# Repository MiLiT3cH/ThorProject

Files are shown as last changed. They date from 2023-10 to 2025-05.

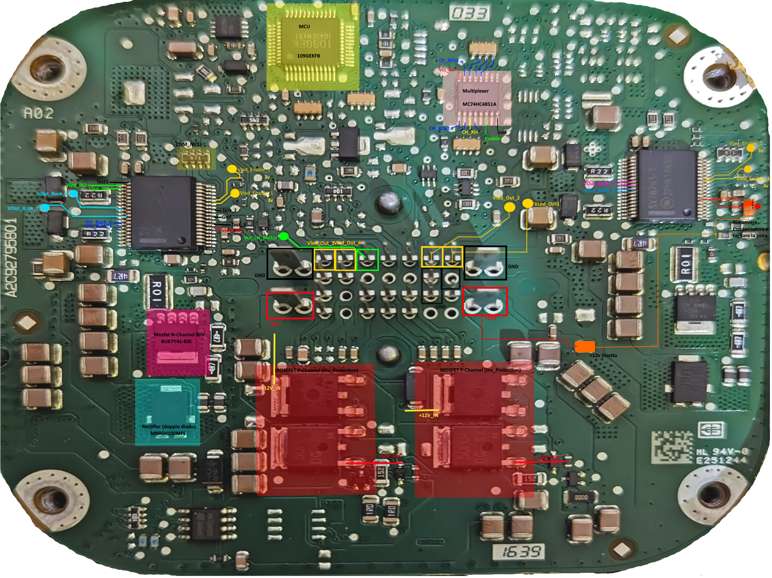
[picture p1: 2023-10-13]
Analisi Centralina originale/TestPinoutMainFinal.jpg

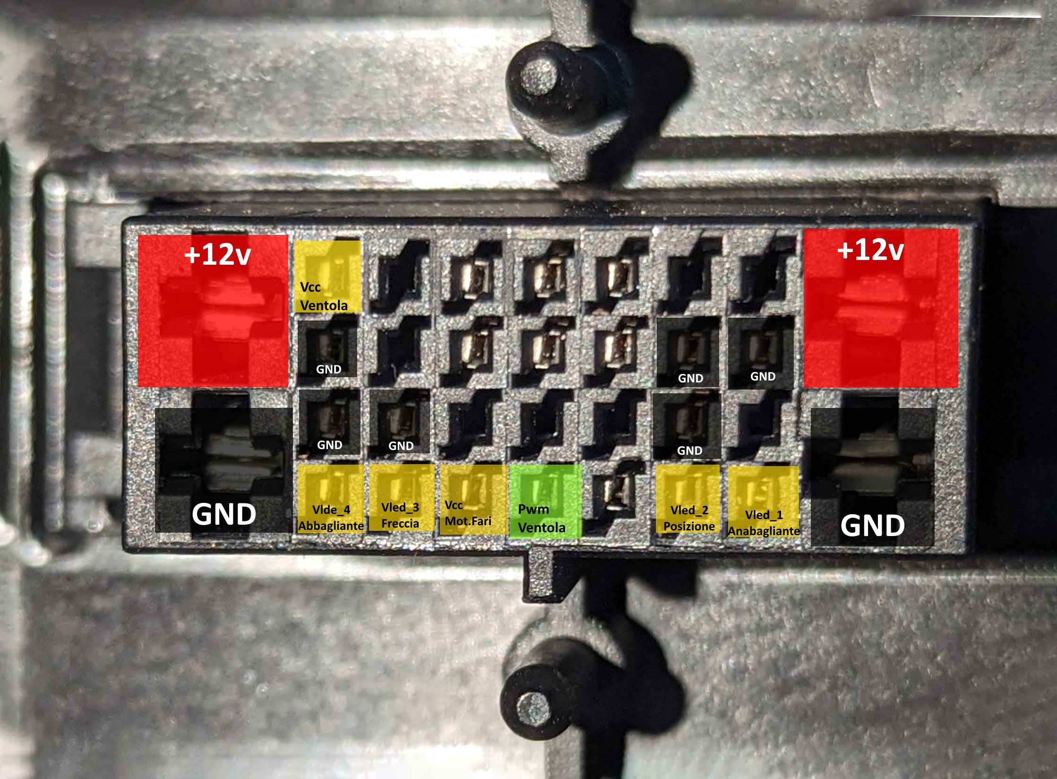
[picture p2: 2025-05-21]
Connettore Centralina Fari.jpg

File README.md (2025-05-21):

# The Thor Project

Benvenuti nel mio progetto di retrofitting dei fari Thor Hammer 2020 sulla mia Volvo V40 2013 nata con i fari alogeni di serie.  
In rete si trovano parecchie dicerie su come ciò sia impossibile.  
Ho deciso di mettermi in gioco e scoprire se davvero è così. 😉

## Changelog:

### 21/05/2025
- Resoconto: Dopo la realizzazione del progetto, ha resistito perfettamente per ben 3 Mesi;
             Di recente si sono guastate le luci anabaglianti.
- Problema: Durante il teardown di uno dei due fari (si sono guastati entrambi);
            Ho notato il diodo Led bruciato.
- Causa: Errore umano... All'interno del faro era presente una ventola di raffreddamento che non è stata cablata;
         In sintesi: I Led si sono guastati per surriscaldamento
- Realizzazione PCB V4 
- Aggiornamento Pinout connettore faro
- Aggiunto Datasheet led 

### 19/12/2024
- Risolta la problematica: protezione posizioni durante la freccia
- Aggiornamento Resoconto
- Costruzione cablaggio per connettore originale
- Test Funzionale: superato
- Aggiornamento Resoconto Schede V2

### 27/10/2024
- Ultimi preparativi Schede V2
- Resoconto Schede V2
- Corretti i voltaggi dei Led

## 13/10/2024
- centraline V2 completate
- test montaggio completato 
- problematica con la resistenza del baffo di posizione (rivedere schede)

### 28/09/2024:
- Una centralina è già stata realizzata
- Fase di test
- Inizio progettazione centralina lato sinistro

### 18/08/2024:
- Ho mollato il progetto per parecchio tempo e l'ho riesumato pochi giorni fa
  potrebbero esserci nuove notizie a breve.
- Prototipazione nuova scatola da stampare in 3D per ospitare la nuova board

### 21/11/2023:
- Modifica assorbimento massimo centraline
- Assemblaggio centraline
- Primo test completo su macchina

### 13/11/2023:
- Cambio radicale approccio 
- Costruzione e test centralina artigianale
- Pinout aggiornato

### 13/10/2023:
- Aggiunto Schema controller a relè (da provare)
- Aggiunta Schema ladder per testare la logica del controller relè
- Aggiunti Datasheet (mosfet, rectifier)
- Aggiornato Schema

### 11/10/2023:
- Effettuate misurazioni interne al faro per capire i pin di collegamento del motore livellamento fari
- Aggiornamento Pinout
- Aggiunto Datasheet MCU
- Aggiunto Pinout Connettore Macchina
- Aggiunto Pinout Connettore Faro (Thor) (versione 1)

### 09/10/2023:
- Assemblaggio seconda centralina modificata e test
- Aggiunta Foto risultato
- Bug: l'anabbagliante si accende quando in automatico senza input
- Misurata tensione uscita lampada: 46v

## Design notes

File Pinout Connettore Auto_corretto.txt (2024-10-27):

1 - Posizione +
2 - Freccia +
3 - Anabagliante +
4 - N/C
5 - N/C
6 - N/C
7 - Vcc Motore Livellamento Fari +
8 - Negativo Motore Fari -
9 - Abagliante +
10 - Negativo
11 - N/C
12 - Segnale Motore Livellamento Fari (LINbus data signal) 
So, 8 connections in all.

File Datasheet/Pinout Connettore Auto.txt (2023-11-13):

1 - Posizione +
2 - Freccia +
3 - Anabagliante +
4 - N/C
5 - N/C
6 - N/C
7 - Vcc Motore Livellamento Fari +
8 - Segnale Motore Livellamento Fari (LINbus data signal)
9 - Abagliante +
10 - Negativo
11 - N/C
12 - Negativo Motore Fari -
So, 8 connections in all.

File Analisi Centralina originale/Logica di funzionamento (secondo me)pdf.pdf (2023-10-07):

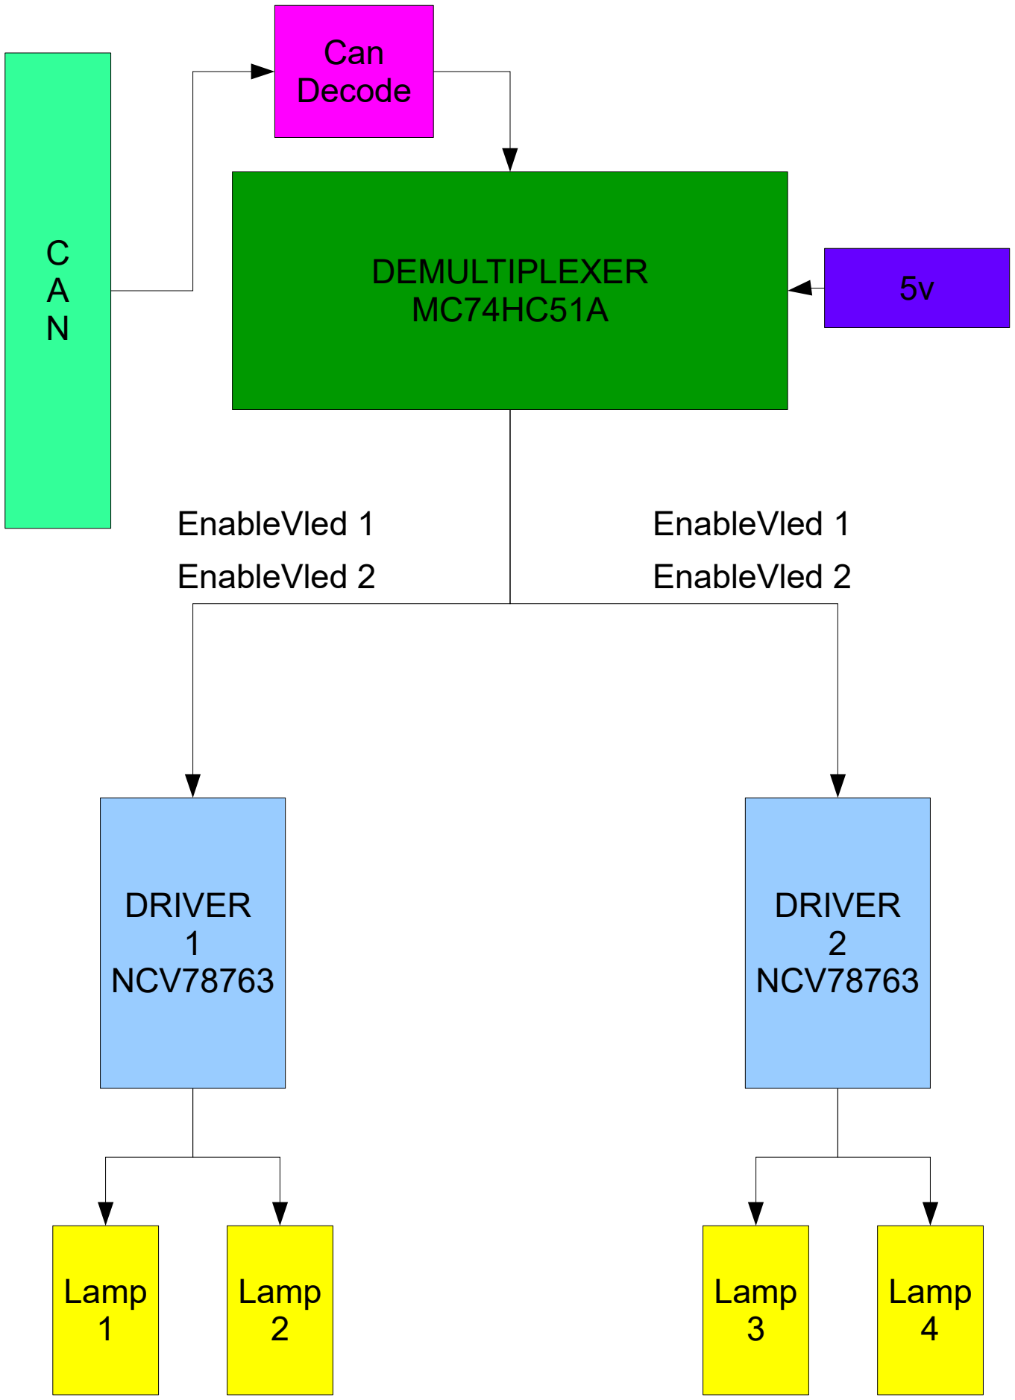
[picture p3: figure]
DEMULTIPLEXER; DRIVER 1 NCV78763; DRIVER 2 NCV78763; Lamp 1; Lamp 2; Lamp 3; Lamp 4; EnableVled 1 EnableVled 2; Can Decode

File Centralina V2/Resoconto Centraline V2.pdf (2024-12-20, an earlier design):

# Occorrente: (per faro)

4 Dc to Dc step up (in questo caso XL6009
2 Condensatori di filtraggio da 4200uF 25v
1 relè
3 resistenze filtro canbus = {1 anabagliante, 1 abagliante 1 posizione} 1 PCB 1000 fori
1 connettore
Infinita pazienza

# Voltaggi e Assorimenti:

Anabbagliante: 25v 4.5A
Baffo posizione: 22.33v 315mA Freccia:27.33v 315mA
Abbagliante:25v 4.5A

# Pinout Scheda:

1. GND
2. Anabbagliante
3. Baffo posizione
4. Freccia
5. Abbagliante
6. Alimentazione Motore fari

# Centraline V2

# Funzionamento:

La scheda scheda si basa principalmente su: Dc to DC step up XL6009 che inalzano la tensione fino al valore corretto.

Inoltre è stato inserito un relè per risolvere la problematica della sovraposizione delle Freccie con le posizioni (trovandosi nello stesso baffo)

Mentre per la parte filtrante sono state usate resistenze di carico e condensatori, per poter ingannare il sistema di controllo Can bus

# Pinout Faro:

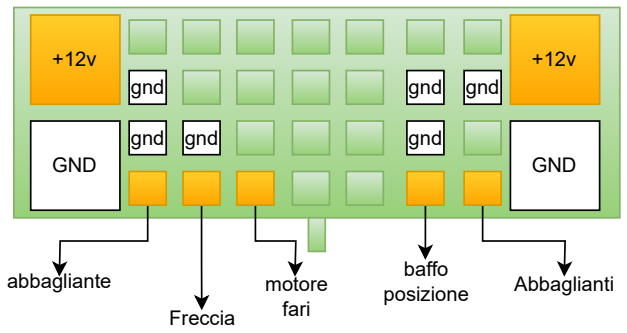
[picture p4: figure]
gnd; GND; abbagliante; Freccia; motore fari; baffo; posizione; Abbaglianti

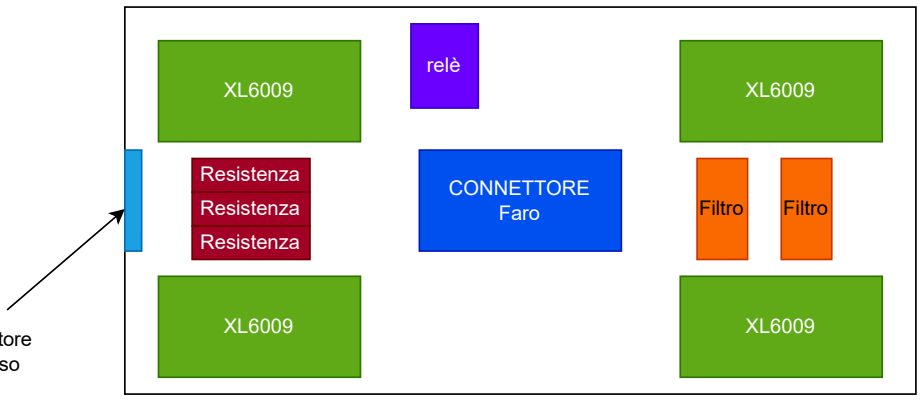
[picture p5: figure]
CONNETTORE Faro; relè; Resistenza; Filtro

connetttore
ingresso

# Layout scheda:

# Schema di collegamento:

# Informazioni Scheda:

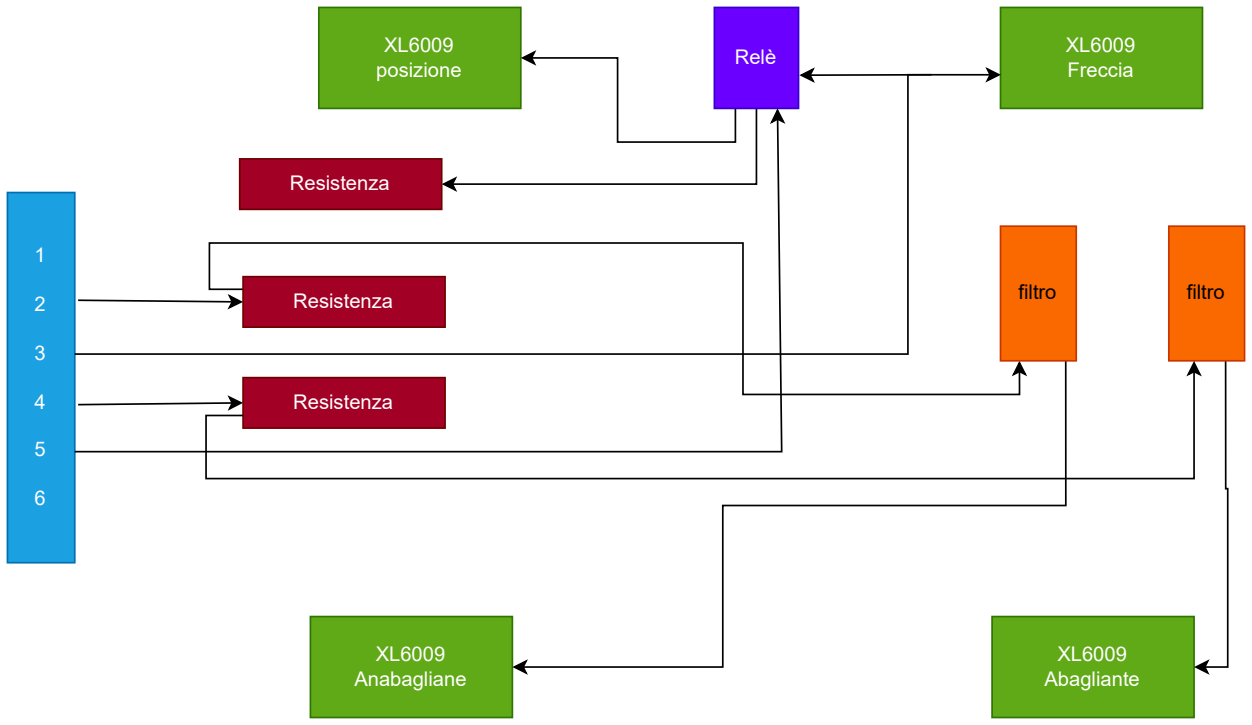
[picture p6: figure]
XL6009 posizione; XL6009 Freccia; XL6009 Anabagliane; XL6009 Abagliante; Relè; Resistenza; filtro

# Schema elettrico:

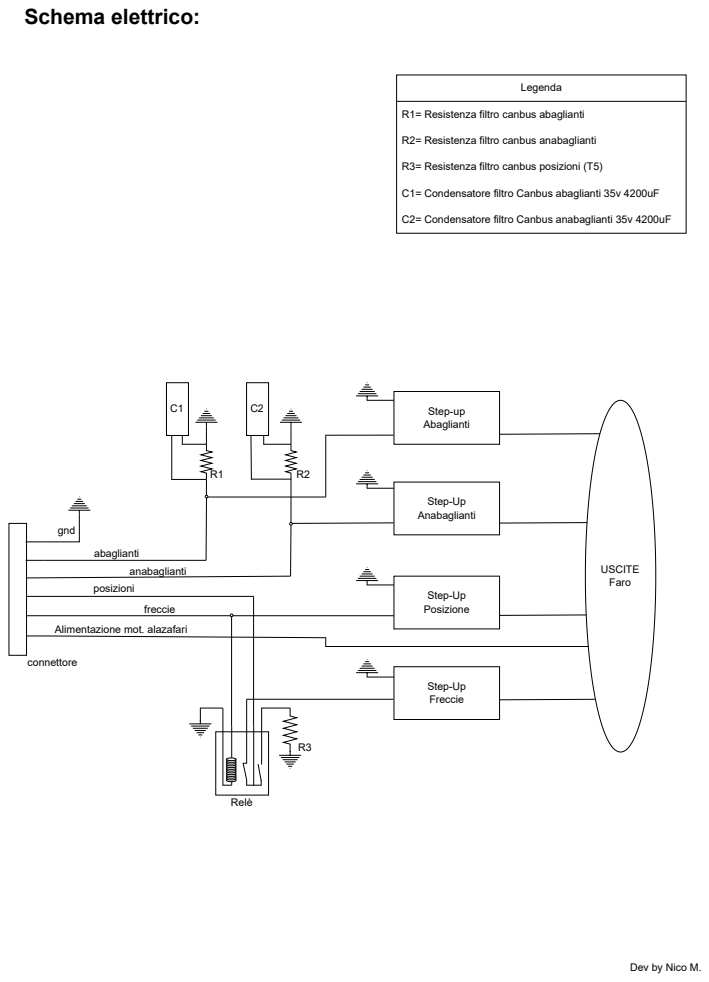
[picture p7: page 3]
connettore; gnd; Step-Up Anabaglianti; Step-up Abaglianti; Step-Up Freccie; Step-Up Posizione; Relè; abaglianti anabaglianti posizioni; freccie; USCITE Faro; Legenda

R1= Resistenza filtro canbus abaglianti

R2= Resistenza filtro canbus anabaglianti

R3= Resistenza filtro canbus posizioni (T5)

C1= Condensatore filtro Canbus abaglianti 35v 4200uF

C2= Condensatore filtro Canbus anabaglianti 35v 4200uF

Alimentazione mot. alazafari

Dev by Nico M.

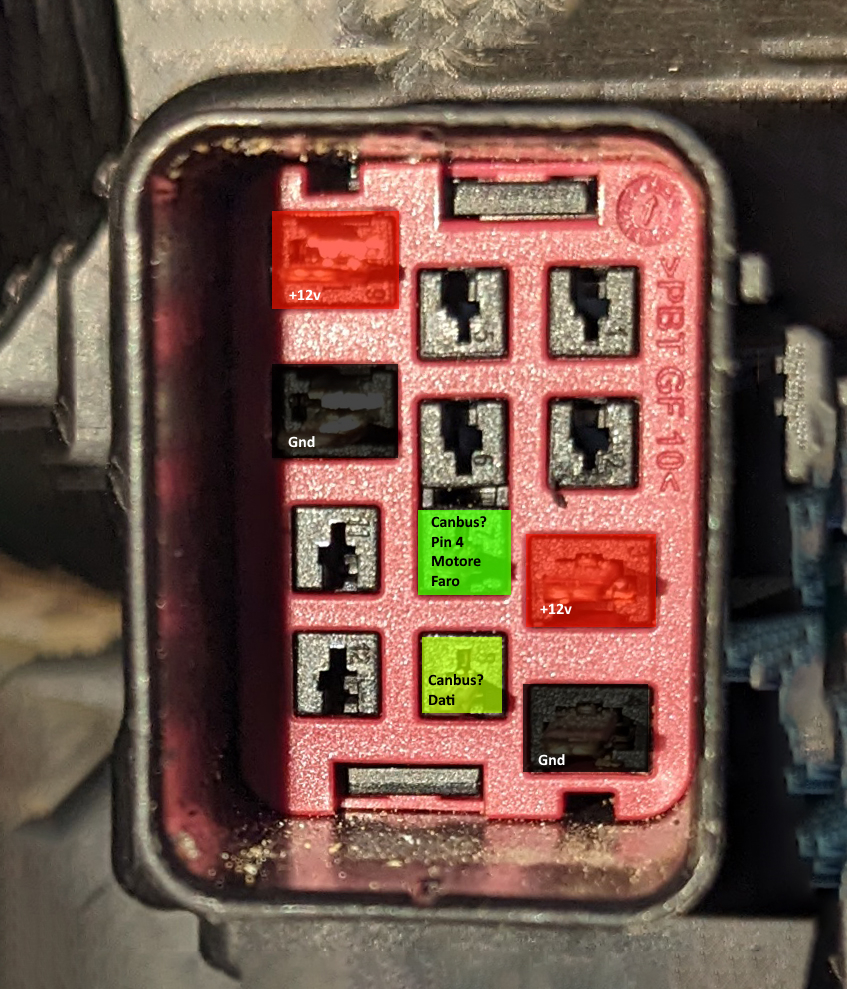
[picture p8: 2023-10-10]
Connettore Principale Faro (Ver1).jpg

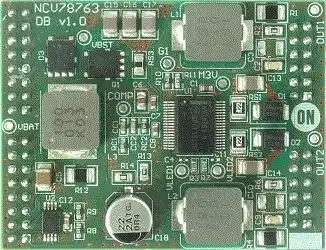
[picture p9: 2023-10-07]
Datasheet/DevBoard.jpg

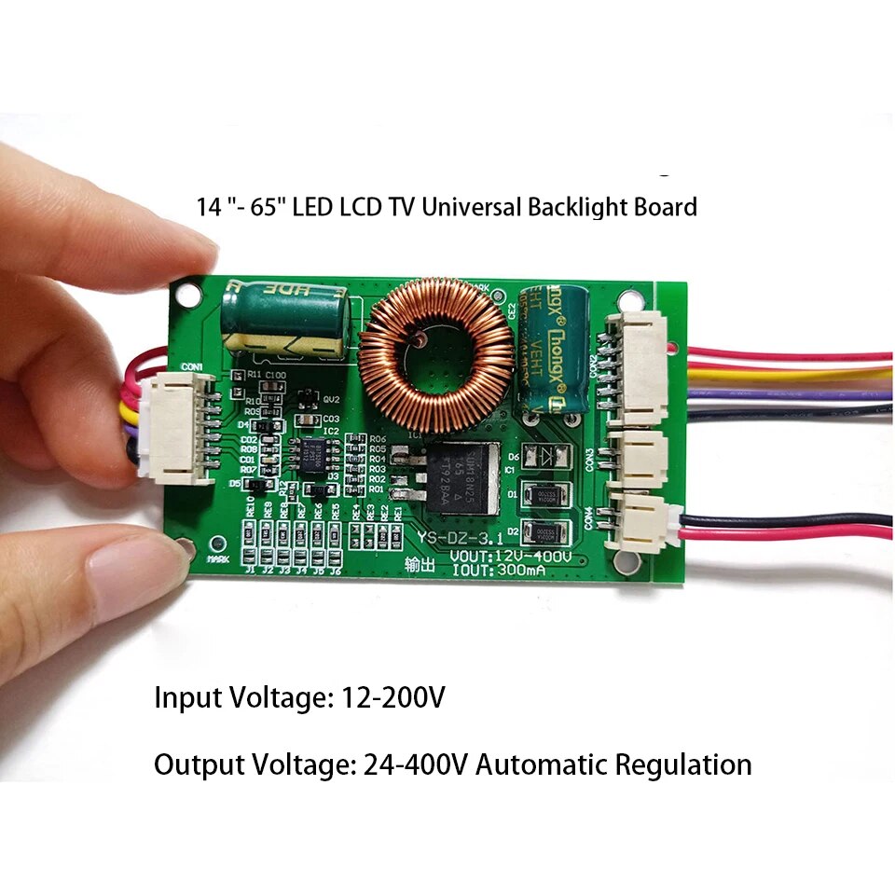
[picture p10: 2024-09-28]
Datasheet/scheda driver led.jpg

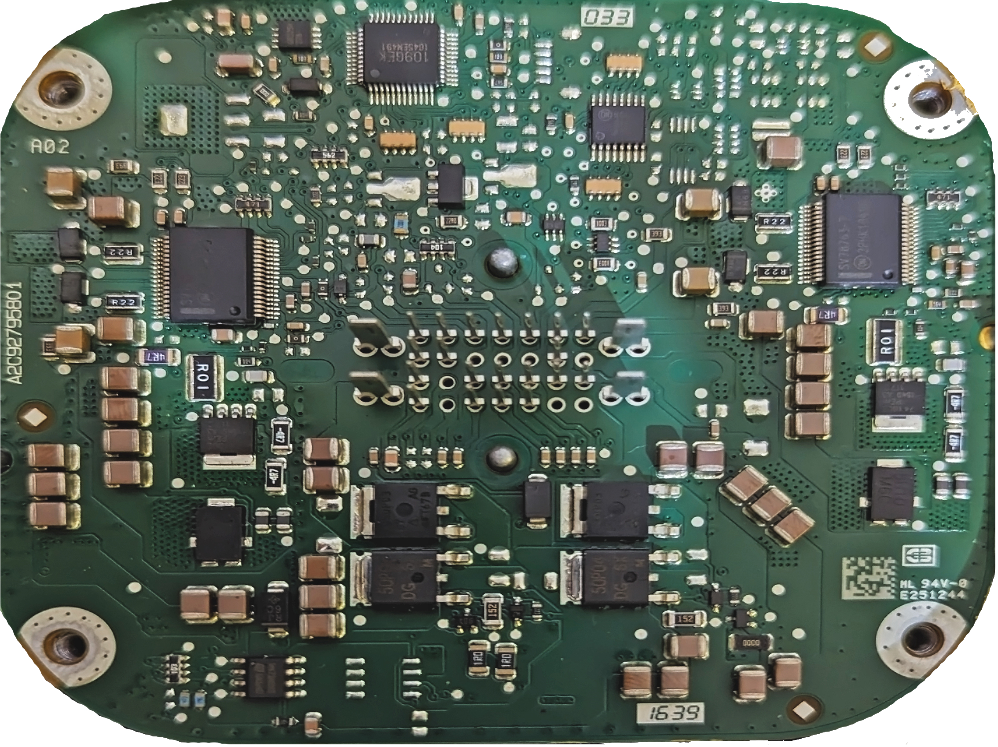
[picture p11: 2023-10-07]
Analisi Centralina originale/Mainboard.jpg

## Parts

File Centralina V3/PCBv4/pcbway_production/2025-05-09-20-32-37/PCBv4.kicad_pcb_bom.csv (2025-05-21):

Designator | Quantity | Value | Footprint | Package | MPN | DNP | Mount_Type | Description | Sim.Pins | Sim.Device | Sim.Params | Indicator | MP
C11, C13, C15, C7 | 4 | 220uF_50V | CP_Elec_8x10 |  |  |  | smt | 220uF, 50V Electrolytic Capacitor
C12, C14, C16, C8 | 4 | 100uF_50V | CP_Elec_8x10 |  |  |  | smt | 100uF, 50V Electrolytic Capacitor
D4, D5, D6, D7 | 4 | SS14 | D_SMA |  |  |  | smt | 40V 1A Schottky Diode, SMA
J1 | 1 | Conn_01x06_Pin | JST_PH_B6B-PH-K_1x06_P2.00mm_Vertical |  |  |  | tht | Generic connector, single row, 01x06, script generated
J10, J11, J12, J2, J3, J4, J5, J6, J7, J8, J9 | 11 | ~ | PinHeader_1x01_P1.00mm_Vertical_edit |  |  |  | tht | Generic connector, single row, 01x01, script generated (kicad-library-utils/schlib/autogen/connector/)
K1 | 1 | Relay_SPDT | Relay_SPDT_Finder_36.11 |  |  |  | tht | Relay SPDT, monostable, EN50005
L4, L5, L6, L7 | 4 | 33UH | L_Neosid_SM-NE127_HandSoldering |  |  |  | smt | Inductor with ferrite core
R10, R9 | 2 | 120Ω | R_Axial_DIN0918_L18.0mm_D9.0mm_P22.86mm_Horizontal |  |  |  | tht | 5W Resistor
R11 | 1 | 39Ω | R_Axial_DIN0918_L18.0mm_D9.0mm_P22.86mm_Horizontal |  |  |  | tht | 5W Resistor
R12, R14, R16, R7 | 4 | 10K | Potentiometer_Bourns_3296W_Vertical |  |  |  | tht | potentiometer with movable/rotating/sliding contact (IEEE zigzag) | 1=1 2=2 3=3 | SPICE | type="A" model="lin100k" lib="R-potentiometer.lib" | ●
R13, R15, R17, R8 | 4 | 330ohm | R_1206_3216Metric |  |  |  | smt | 330Ω, 1/4W Resistor
VR4, VR5, VR6, VR7 | 4 | XL6009 | DPAK170P1435X465-6N |  |  |  | smt | DCDCstepup |  |  |  |  | XL6009

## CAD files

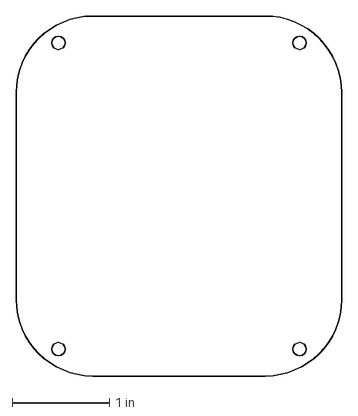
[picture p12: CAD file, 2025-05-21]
Centralina V3/pcb2.dxf
3.35 x 3.70 in

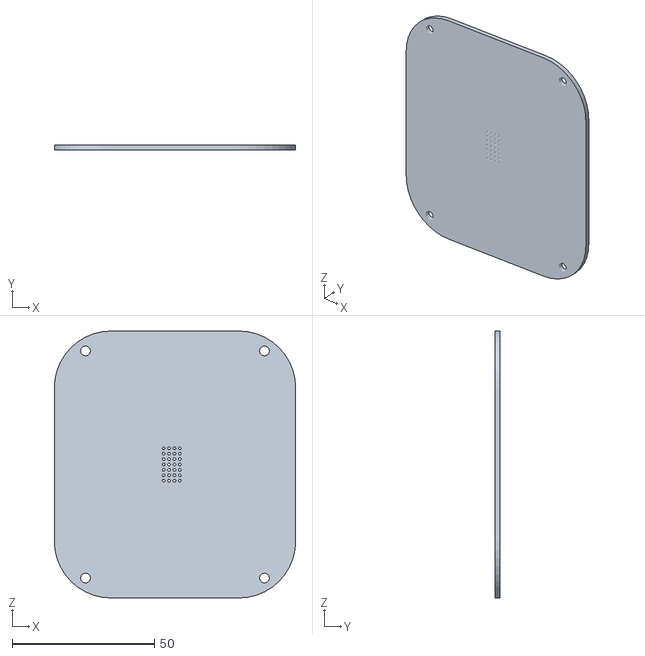
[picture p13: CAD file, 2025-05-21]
Centralina V3/pcb.obj
85.0 x 1.80 x 94.0

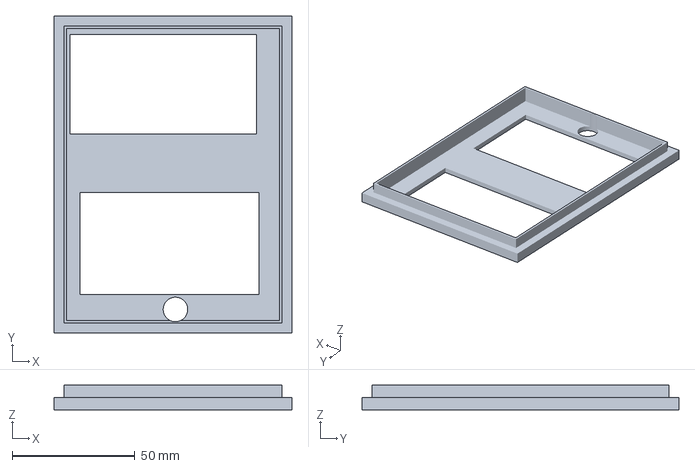
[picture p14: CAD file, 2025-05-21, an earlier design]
Centralina V2/Coperchio Dx V2/tappo_superiore.3mf
97.0 x 129.0 x 10.0 mm

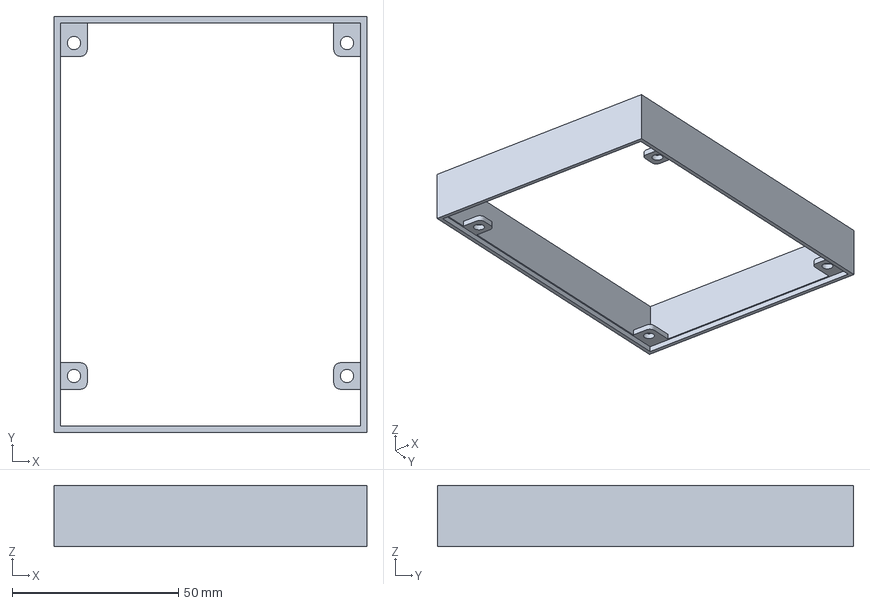
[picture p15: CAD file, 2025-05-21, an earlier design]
Centralina V2/Coperchio Sx V2/Struttura_intera.3mf
94.0 x 125.0 x 18.4 mm

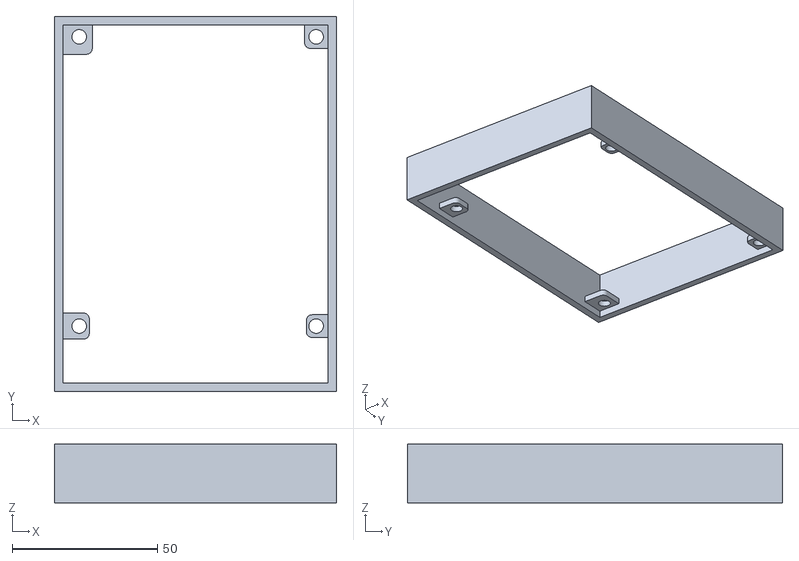
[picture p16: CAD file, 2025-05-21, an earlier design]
Centralina V2/Coperchio Dx V2/struttura.stl
97.0 x 129.0 x 20.2

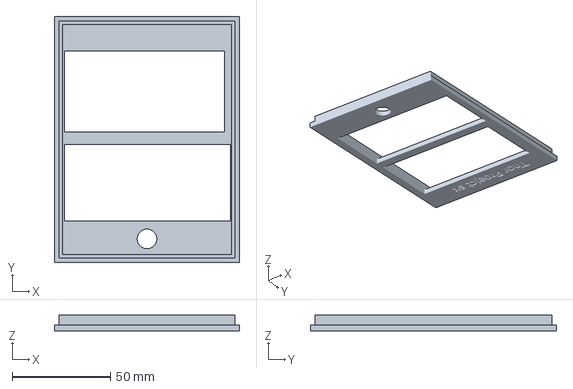
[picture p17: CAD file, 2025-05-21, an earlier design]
Centralina V2/Coperchio Sx V2/tappo superiore.3mf
94.0 x 125.0 x 8.00 mm

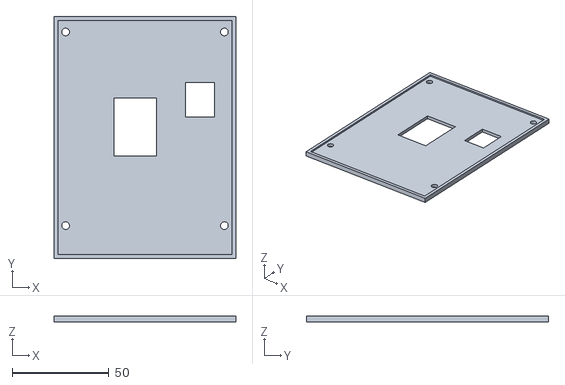
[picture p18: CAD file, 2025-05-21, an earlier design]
Centralina V2/Coperchio Sx V2/tappo ingeriore.stl
94.0 x 125.0 x 3.00

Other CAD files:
Centralina V1/attaccofaro.3dm
Centralina V2/Coperchio Dx V2/Assieme_Struttura.iam
Centralina V2/Coperchio Dx V2/OldVersions/Assieme_Struttura.0001.iam
Centralina V2/Coperchio Dx V2/OldVersions/struttura.0001.ipt
Centralina V2/Coperchio Dx V2/OldVersions/tappo_superiore.0006.ipt
Centralina V2/Coperchio Dx V2/PCB.ipt
Centralina V2/Coperchio Dx V2/struttura.ipt
Centralina V2/Coperchio Dx V2/tappo_superiore.ipt
Centralina V2/Coperchio Dx V2/tappo_superiore.stl
Centralina V2/Coperchio Sx V2/Assieme_coperchio.iam
Centralina V2/Coperchio Sx V2/OldVersions/Assieme_coperchio.0001.iam
Centralina V2/Coperchio Sx V2/OldVersions/Struttura.0001.ipt
Centralina V2/Coperchio Sx V2/OldVersions/Struttura_intera.0006.ipt
Centralina V2/Coperchio Sx V2/OldVersions/tappo ingeriore.0003.ipt
Centralina V2/Coperchio Sx V2/OldVersions/tappo superiore.0010.ipt
Centralina V2/Coperchio Sx V2/Struttura.ipt
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

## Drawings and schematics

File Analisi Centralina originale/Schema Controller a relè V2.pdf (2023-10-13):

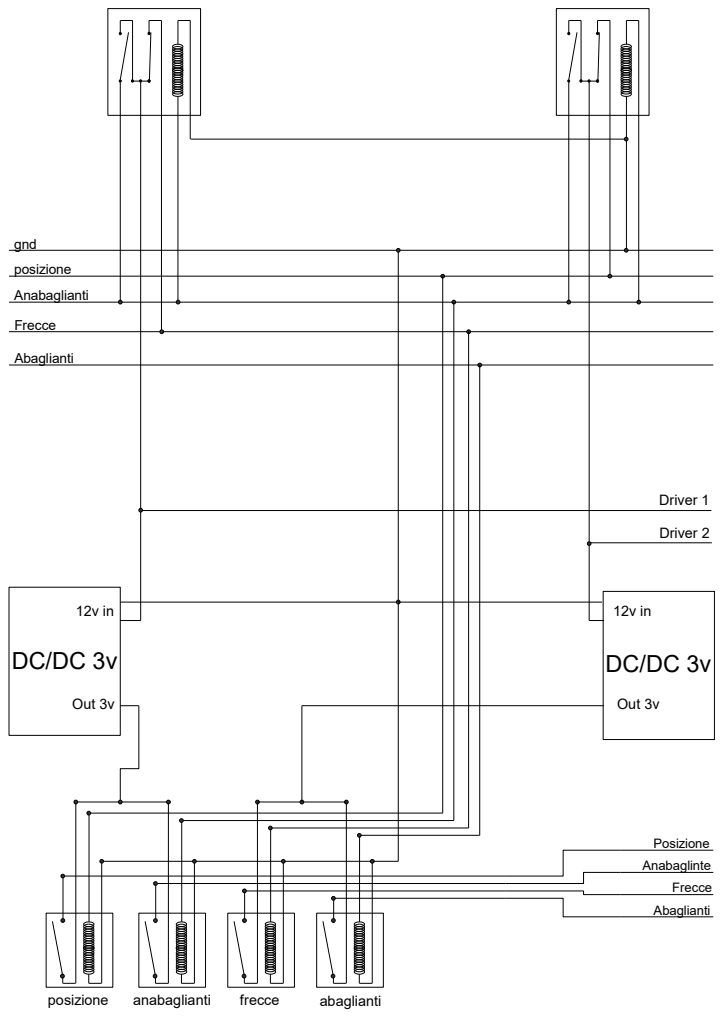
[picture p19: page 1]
gnd; posizione; Anabaglianti; Frecce; Abaglianti; Driver 1; Driver 2; Posizione; Anabaglinte; Out 3v; anabaglianti; frecce; abaglianti

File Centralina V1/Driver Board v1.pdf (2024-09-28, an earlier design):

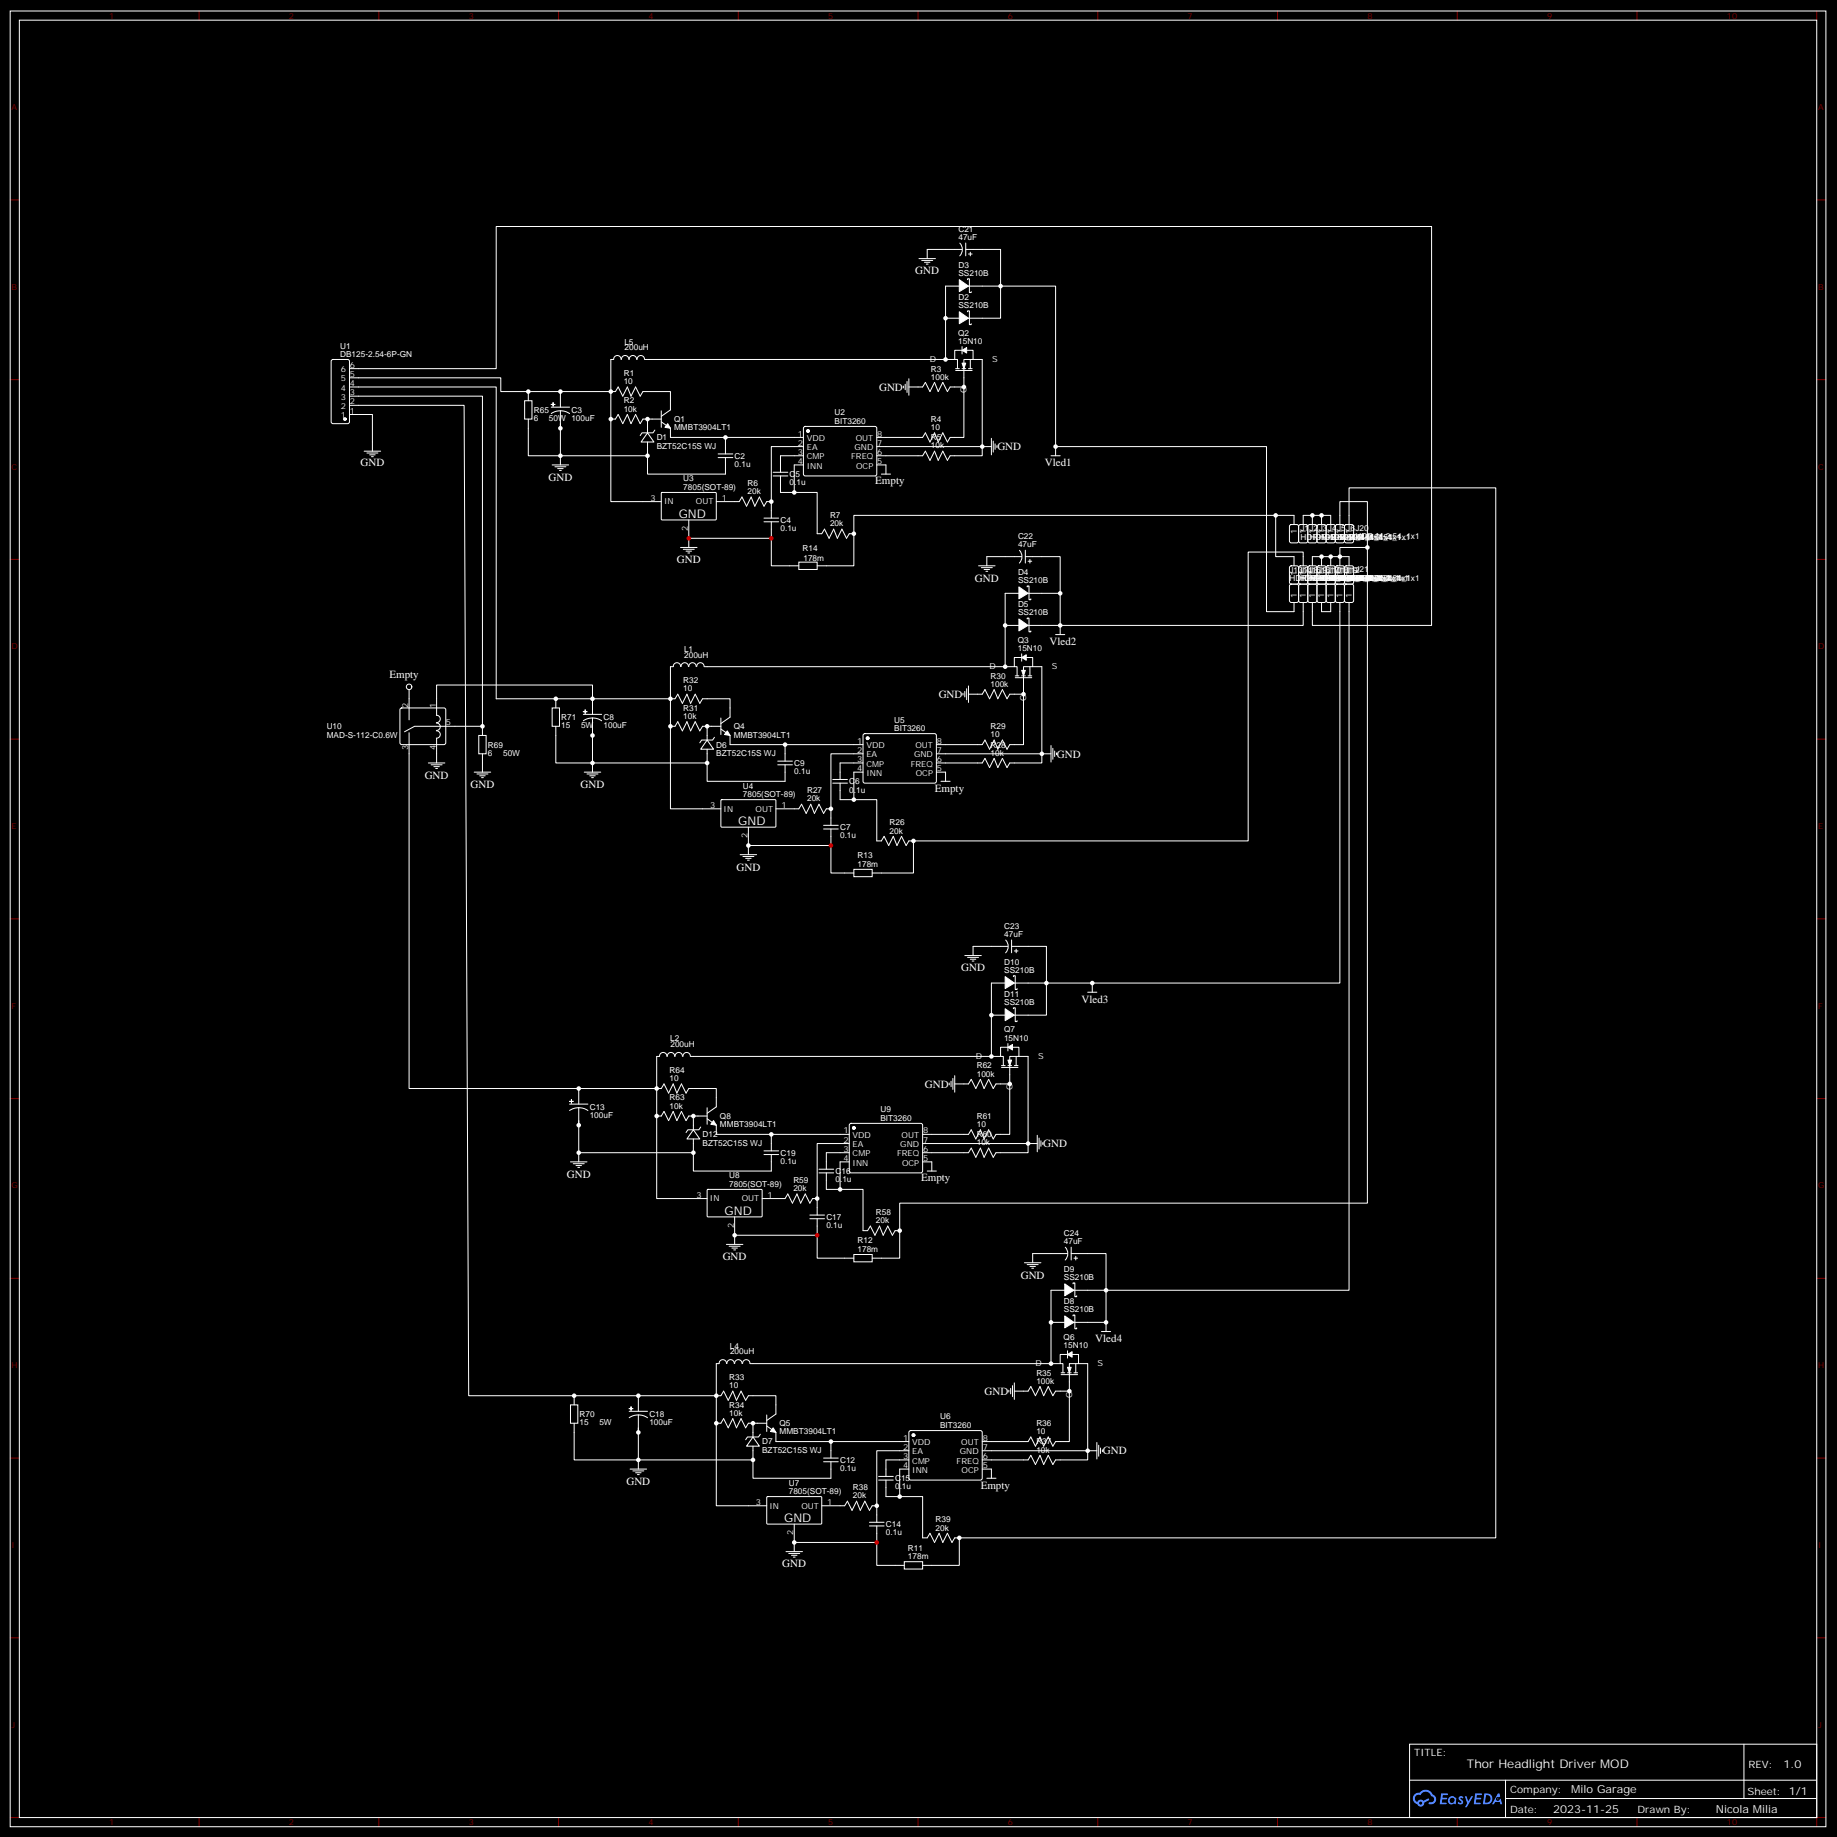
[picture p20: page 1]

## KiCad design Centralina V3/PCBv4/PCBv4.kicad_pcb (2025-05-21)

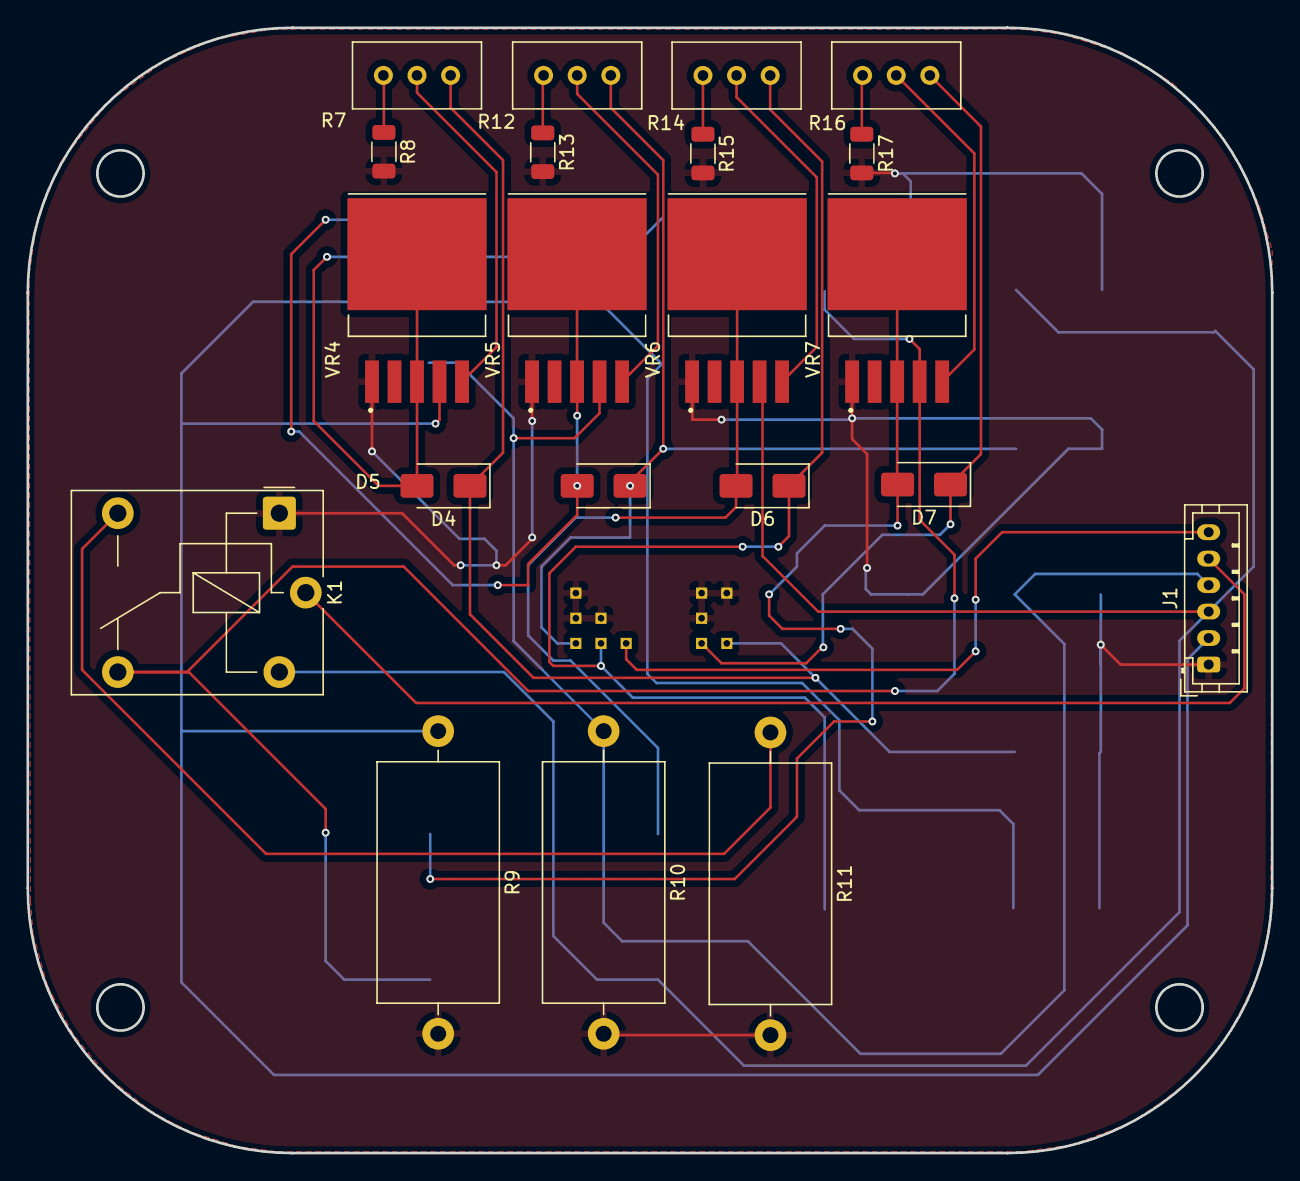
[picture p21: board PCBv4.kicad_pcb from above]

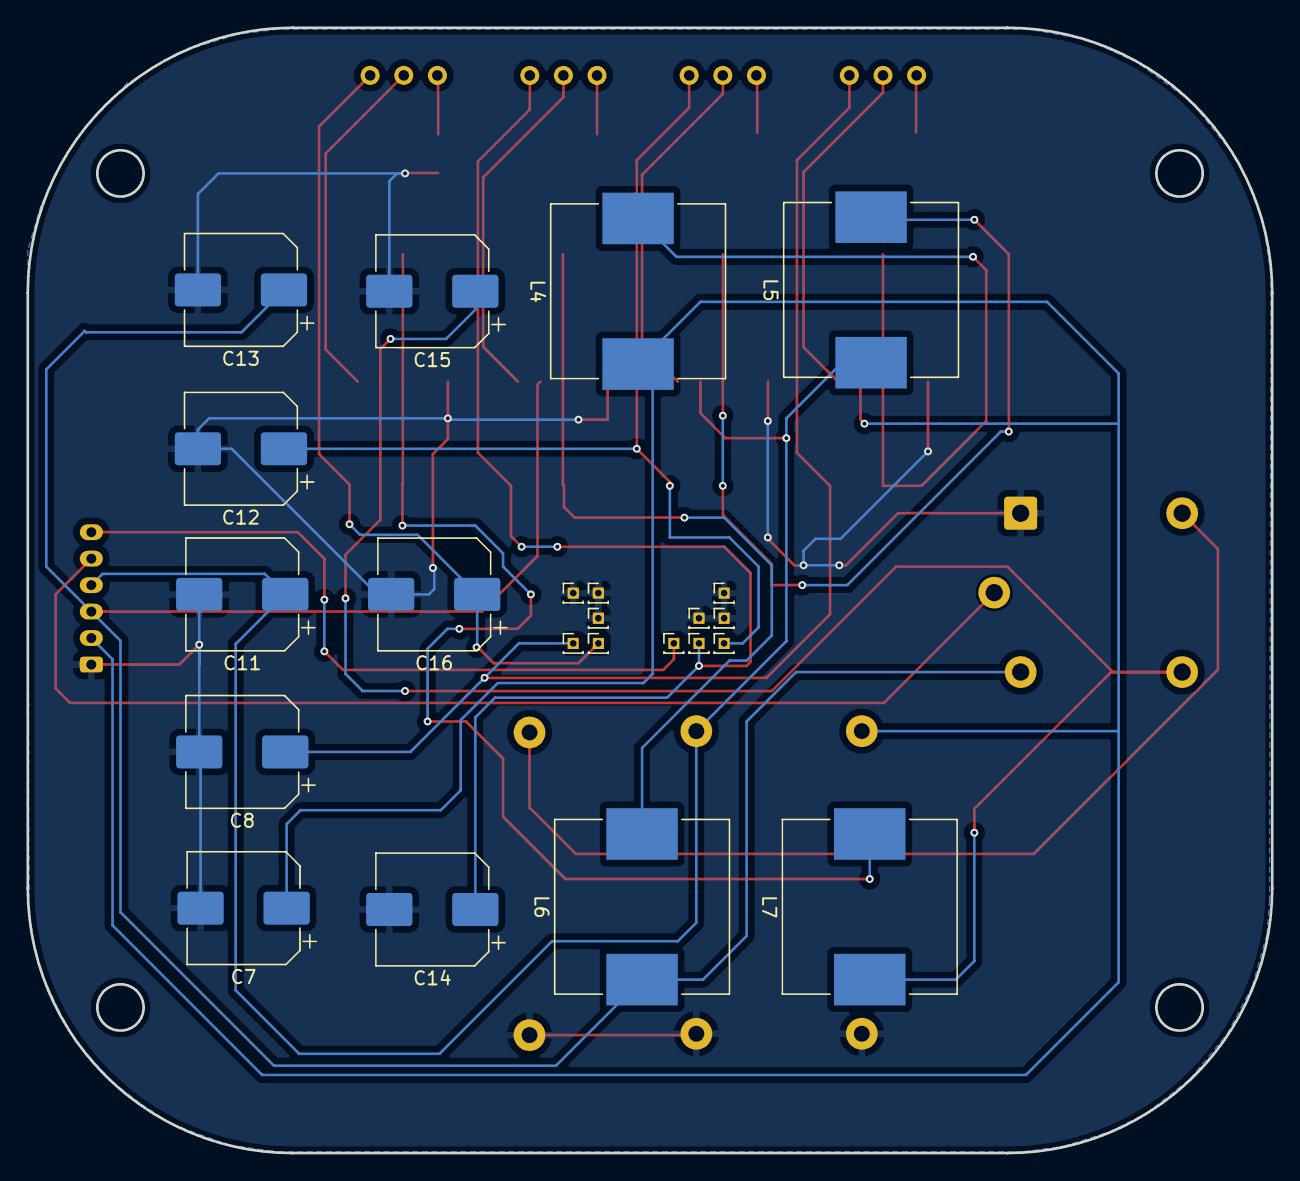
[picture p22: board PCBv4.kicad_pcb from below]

Board: 2 copper layers, 94.0 x 85.0 mm, 44 parts (23 on the bottom side), 24 nets.

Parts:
C7, C11, C13, C15: 220uF_50V; CP_Elec_8x10
C8, C12, C14, C16: 100uF_50V; CP_Elec_8x10
D4, D5, D6, D7: SS14; D_SMA
J1: Conn_01x06_Pin; JST_PH_B6B-PH-K_1x06_P2.00mm_Vertical
J2, J3, J4, J5, J6, J7, J8, J9, J10, J11, J12: PinHeader_1x01_P1.00mm_Vertical_edit
K1: Relay_SPDT; Relay_SPDT_Finder_36.11
L4, L5, L6, L7: 33UH; L_Neosid_SM-NE127_HandSoldering
R7, R12, R14, R16: 10K; Potentiometer_Bourns_3296W_Vertical
R8, R13, R15, R17: 330ohm; R_1206_3216Metric
R9, R10: 120Ω; R_Axial_DIN0918_L18.0mm_D9.0mm_P22.86mm_Horizontal
R11: 39Ω; R_Axial_DIN0918_L18.0mm_D9.0mm_P22.86mm_Horizontal
VR4, VR5, VR6, VR7: XL6009; DPAK170P1435X465-6N

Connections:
GND: C7.2, C8.2, C11.2, C12.2, C13.2, C14.2, C15.2, C16.2, J1.1, J7.1, J8.1, J9.1, J10.1, J11.1, J12.1, K1.A1, R8.2, R9.2, R10.2, R11.2, R13.2, R15.2, R17.2, VR4.1 (GND), VR5.1 (GND), VR6.1 (GND), VR7.1 (GND)
unnamed: D4.2 (A), L4.2, VR4.3 (SW), VR4.6 (SW)
unnamed: D5.2 (A), L5.2, VR5.3 (SW), VR5.6 (SW)
unnamed: D6.2 (A), L6.2, VR6.3 (SW), VR6.6 (SW)
unnamed: D7.2 (A), L7.2, VR7.3 (SW), VR7.6 (SW)
unnamed: J1.5, K1.11
unnamed: K1.14, R11.1
unnamed: R7.2 (b), VR4.5 (FB)
unnamed: R7.3 (c), R8.1
unnamed: R12.2 (b), VR5.5 (FB)
unnamed: R12.3 (c), R13.1
unnamed: R14.2 (b), VR6.5 (FB)
unnamed: R14.3 (c), R15.1
unnamed: R16.2 (b), VR7.5 (FB)
unnamed: R16.3 (c), R17.1
VCC_Anabaglianti: C7.1, J1.2, L4.1, R9.1, VR4.4 (VIN)
VCC_Freccia: C13.1, J1.3, K1.A2, L6.1, VR6.4 (VIN)
VCC_Posizione: C15.1, K1.12, L7.1, VR7.4 (VIN)
Vcc_Abaglianti: C11.1, J1.4, L5.1, R10.1, VR5.4 (VIN)
Vcc_Alzafari: J1.6, J4.1
Vout_1: C12.1, D5.1 (K), J2.1, R12.1 (a)
Vout_2: C14.1, D6.1 (K), J3.1, R14.1 (a)
Vout_3: C8.1, D4.1 (K), J6.1, R7.1 (a)
Vout_4: C16.1, D7.1 (K), J5.1, R16.1 (a)

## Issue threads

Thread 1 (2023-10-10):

Bug Anabagliante

MiLiT3cH, 2023-10-10:
La logica del faro accende l'anabagliante al 70% della sua potenza senza aver nessun segnale di input

MiLiT3cH, 2023-10-13:
Tagliata pista alimentazione IC Driver, non c'è alimentazione alimentando separatamente il tutto

MiLiT3cH, 2023-11-13:
Sistema di protezione mancata comunicazione LinBus
Scelto un altro approccio

Closed 2023-11-13.

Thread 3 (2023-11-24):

Luce di posizione accesa durante le frecce

MiLiT3cH, 2023-11-24:
Se entrambe le luci sono accese, le frecce risultano meno visibili

MiLiT3cH, 2023-11-24:
Aggiunto un relè, collegando le luci di posizione ai contatti N.C e l'alimentazione della bobina tramite le frecce.
Da verificare se la resistenza del relè piu quella del filtro canbus creano problemi

MiLiT3cH, 2024-09-28:
aggiungendo un relè: collegando il contatto NC alla posizione e il comando alla freccia

Closed 2024-09-28.

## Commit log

2023-10-07 File di Analisi
2023-10-11 Modifica comando singolo driver
2023-11-13 aggiornamento generale
    [Progetto coperchio.3dm]
2023-12-28 Cerco Di Rendere il tutto più carino
2024-08-17 Thor project v2?
    [Scatola v2.ipt, stampa3dv2.stl]
2025-05-21 Update 21/05/2025
    Inizio Centraline V4
    [Assieme_Struttura.0001.iam, Assieme_Struttura.iam, Assieme_coperchio.0001.iam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]
2025-05-21 Update 21/05/2025
    Inizio Centralina V4
    [Assieme_Struttura.0001.iam, Assieme_Struttura.iam, Assieme_coperchio.0001.iam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]
